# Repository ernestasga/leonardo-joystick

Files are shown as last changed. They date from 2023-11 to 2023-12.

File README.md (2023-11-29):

# Custom Arduino Leonardo Joystick
This is a custom Arduino Leonardo Joystick. It is based on the Arduino Leonardo and uses the Arduino Joystick library.

| | | |
|:---:|:---:|:---:|
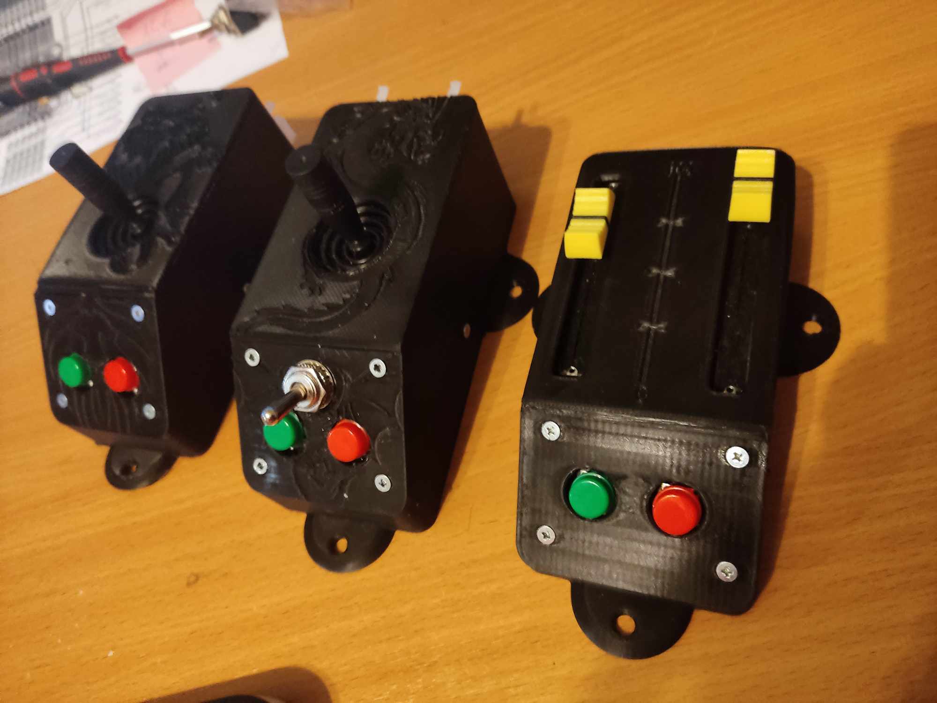
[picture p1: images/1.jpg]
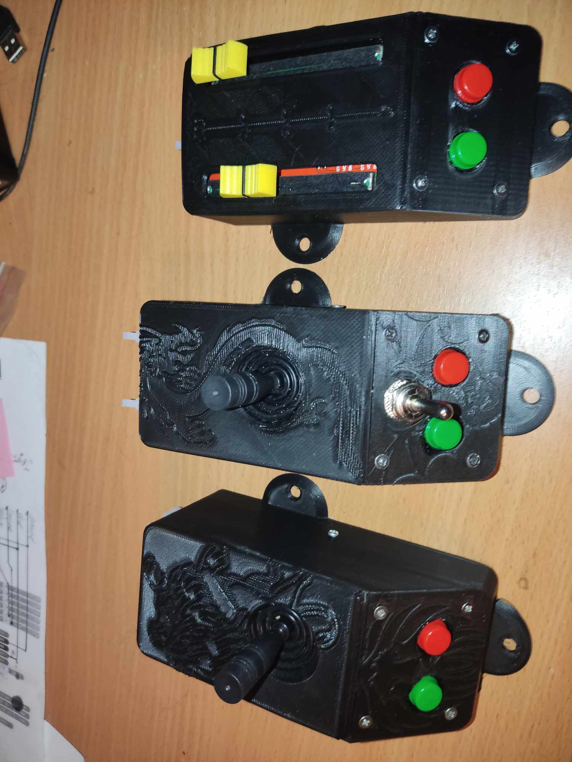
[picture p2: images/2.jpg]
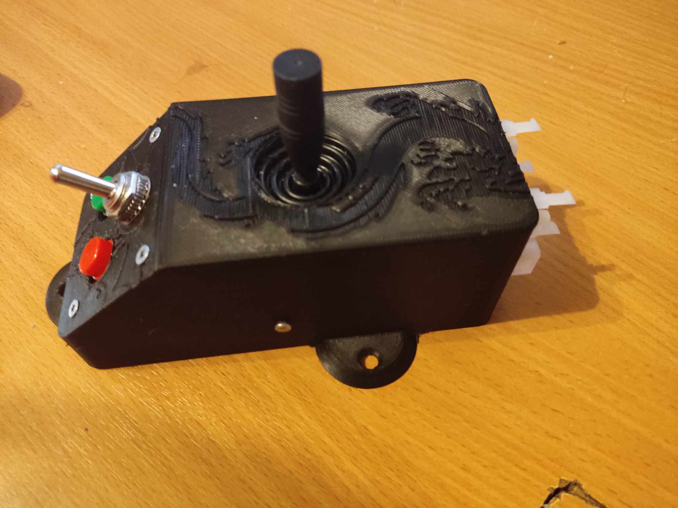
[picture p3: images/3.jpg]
|  |  ||
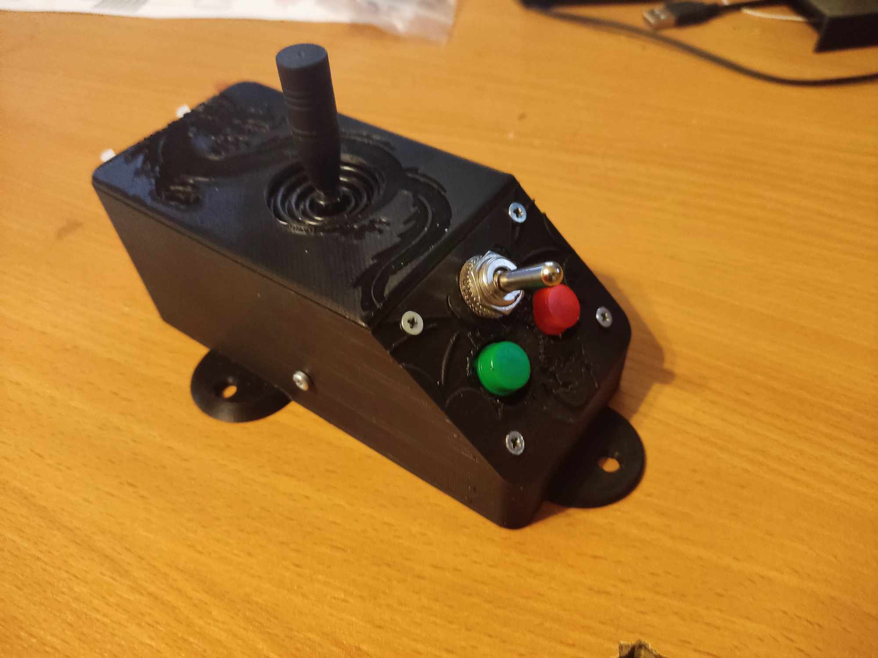
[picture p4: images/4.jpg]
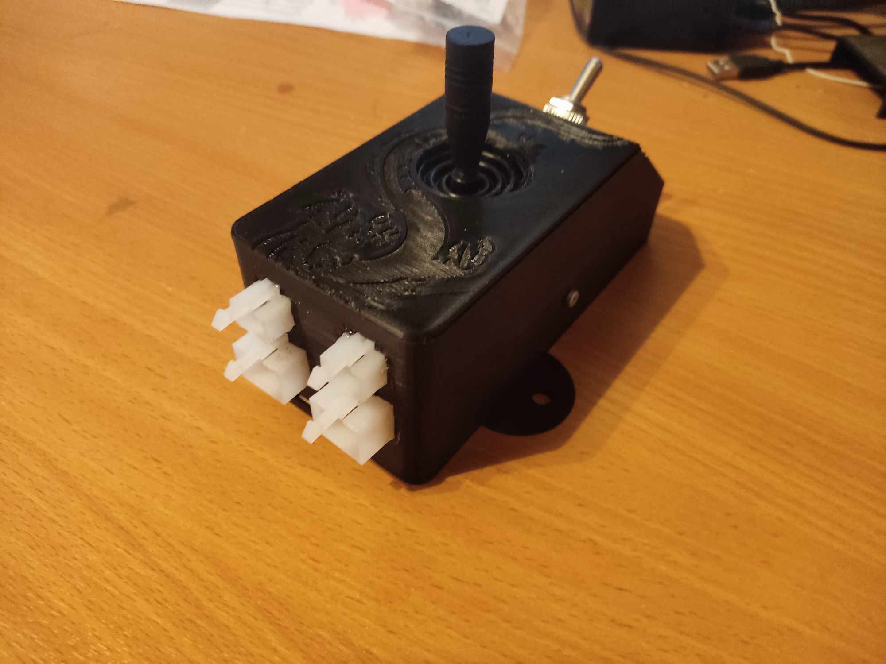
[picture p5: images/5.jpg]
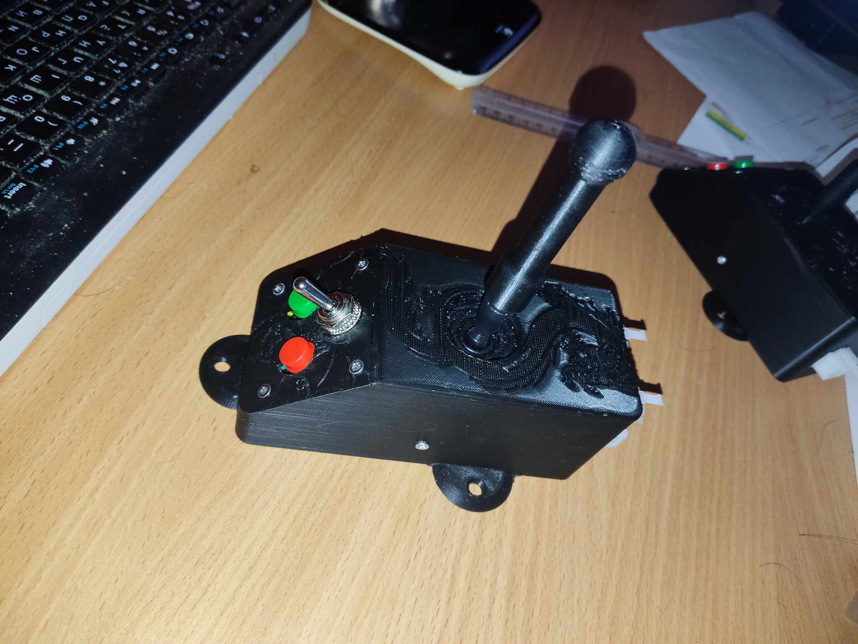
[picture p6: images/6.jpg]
|  |  |  |

## Overview
Joystick is built with accessibility and modularity in mind.

## Parts
- [Arduino Leonardo](https://store.arduino.cc/products/arduino-leonardo-without-headers)
- 2x [2-axis potentiometers](https://www.aliexpress.com/item/1005005203342038.html)
- 2x [slider potentiometers](https://www.aliexpress.com/item/1005005434366252.html)
- 6x [tactile arduino buttons with caps](https://www.aliexpress.com/item/1005005708818336.html)
- 1x [mini toggle switch](https://www.aliexpress.com/item/1005004692981776.html)
- [6 core cable](https://www.aliexpress.com/item/4000570401041.html) (for connecting the joystick and buttons, ~5M)
- [2 core cable](https://www.aliexpress.com/item/4000570401041.html) (for connecting the external buttons, ~5M)
- 5x [6-pin connectors](https://www.aliexpress.com/item/1005004615687476.html)
- 2x [2-pin connectors](https://www.aliexpress.com/item/1005004615687476.html)
- 16x M3 screws (12x for button plates, 4x for joystick raisers)
- 4x M3 nuts (for securing joystick raisers)
- Some super glue

## 3D Printed Parts
- **Main case**: Contains the controller board, a joystick and 3 buttons. There are also 2 additional ports for extra joysticks and 2 ports for external buttons.
    * Main Case.stl
    * Top Cover.stl
    * Buttons Plate.stl (Print in ABS. Screw threads don't work well in PLA)
    * Joystick Raiser.stl
    * 4x Arduino Pin Cap.stl (For pushing down the Arduino board)

- **Secondary case**: Contains a joystick and 2 buttons. Connected with one of 6-pin ports on main case.
    * Secondary Case.stl
    * Top Cover.stl
    * Buttons Plate.stl (Print in ABS. Screw threads don't work well in PLA)
    * Joystick Raiser.stl

- **Slider case**: Contains 2 slider potentiometers and 2 buttons. Connected with one of 6-pin ports on main case.
    * Slider Case.stl
    * Top Cover.stl
    * Buttons Plate.stl (Recommended to print in ABS)

## Assembly
1. Solder the wires to the Arduino Leonardo board. Wiring rules are in the `Arduino Leonardo Wiring.pdf` file.
2. Connect other ends of wires to 6-pin and 2-pin connectors on the main case. Lookup `Connector Color Coding.png` for the color coding.
3. Insert the Arduino Leonardo board into the main case. Use 4x Arduino Pin Caps to push the board down.
4. Prepare joystick raisers:
    1. Insert M3 nuts into the inside of the joystick raisers. Use super glue to secure them.
    2. Screw the joystick raisers to the main case.
5. Insert the joystick into and connect it to the ardunio board. When lined up with top cover, super guide the joystick raiser.
6. Connect the 6-pin connectors to the secondary and slider cases. (Optional) Connect the 2-pin connectors to the external buttons.

For secondary case and slider case, you can use the same steps as for the main case. The only difference is that you don't need to insert the Arduino board into the case and there are much less wires to connect.

## Flashing the Arduino
1. Download and install the Arduino IDE from https://www.arduino.cc/en/Main/Software
2. Install the Arduino Joystick library:
    1. Download the Arduino Joystick library from [Github Repo](https://github.com/MHeironimus/ArduinoJoystickLibrary/releases/)
    2. Extract the library to `~/Documents/Arduino/libraries/`
3. Open the `code/main/main.ino` file in the Arduino IDE
4. Select "Arduino Leonardo" from the Tools > Board menu
5. Select your Arduino Leonardo's serial port from the Tools > Port menu
6. Invert axes and modify deadzones if needed at lines 95-100.
7. Press the "Upload" button

## Customization
### Code
You can customize the joystick functionality by modifying the `code/main/main.ino` file. You can change the button mappings, invert axes, modify deadzones and more.

### 3D Models
You can modify the 3D models by opening the `3D/src/Joystick.3df` file in Autodesk [Fusion 360](https://www.autodesk.com/products/fusion-360/overview) or `3D/src/Joystick.step` file in any other 3D modeling software.

Specifically, you may want to modify case engravings. They can be found at the end of each component' timeline. SVG files for engravings can be found in the `3D/src/svg` folder.

## Usage
The joystick is recognized as a standard HID USB joystick. You can use it in any game or application that supports joysticks.

Here is a list of complimentary software that can be used with the joystick for accessibility purposes:
- [Xpadder](https://www.xpadder.com/) - Allows you to map keyboard keys and mouse button actions to your game controller buttons.
- [x360ce](https://www.x360ce.com/) - Allows you to emulate an Xbox controller with any controller.
- [JoyToKey](https://joytokey.net/en/) - Allows you to map keyboard keys and mouse button actions to your game controller buttons.

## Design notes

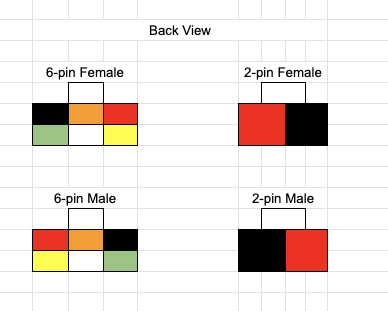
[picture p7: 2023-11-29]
Connector Color Coding.png

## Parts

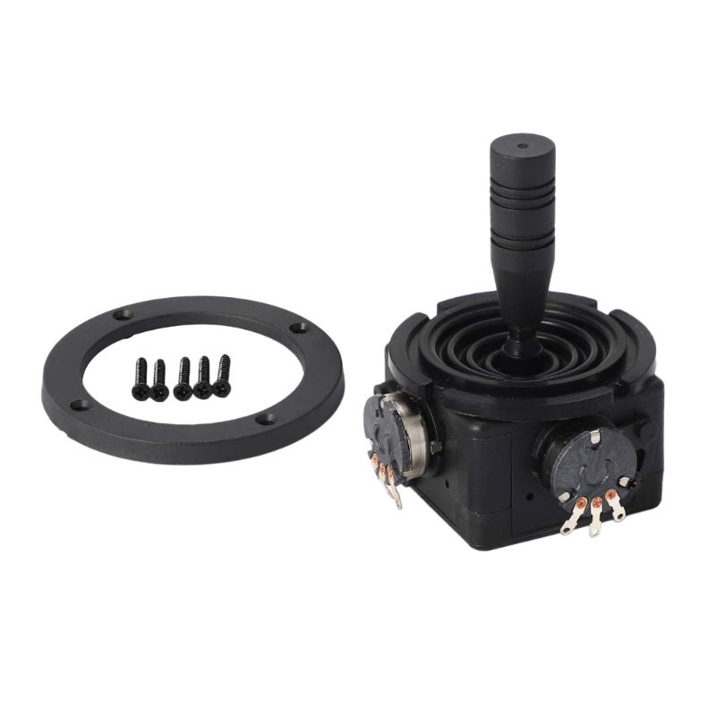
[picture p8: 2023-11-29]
parts/Joystick JH-D202X-R4.png

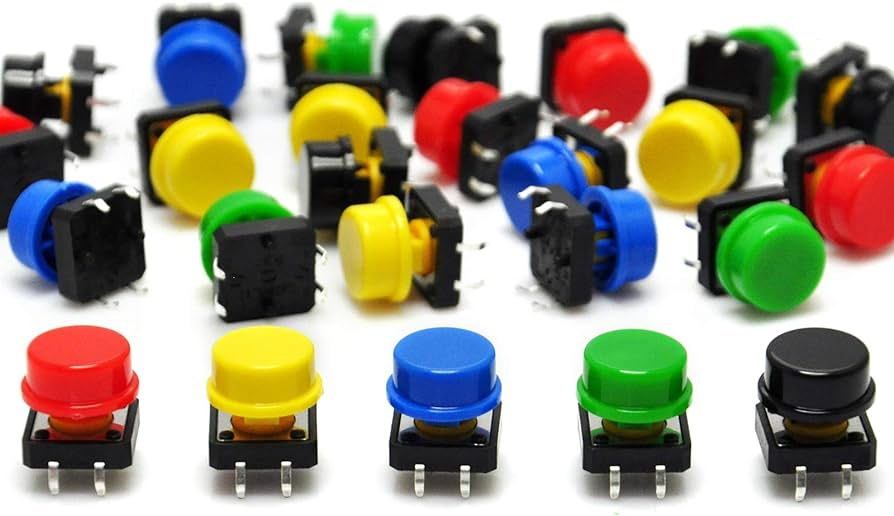
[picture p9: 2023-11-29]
parts/Buttons.png

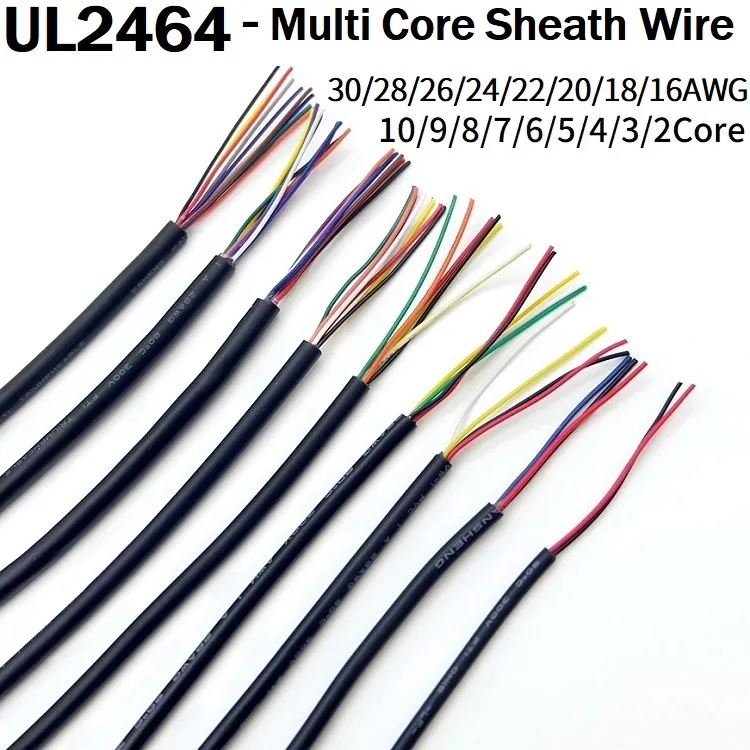
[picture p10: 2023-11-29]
parts/Cables.png

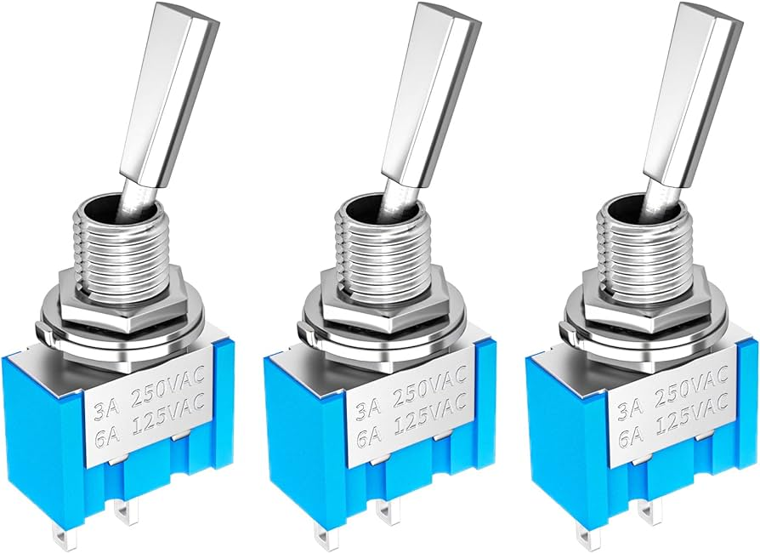
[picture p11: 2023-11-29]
parts/Mini Toggle Switch.png

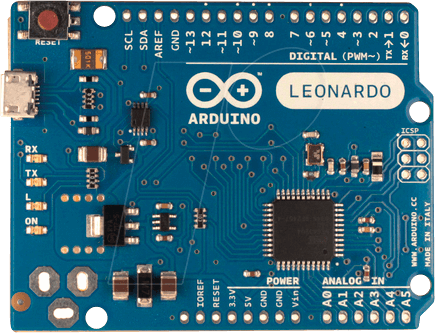
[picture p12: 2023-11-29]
parts/Arduino Leonardo.png

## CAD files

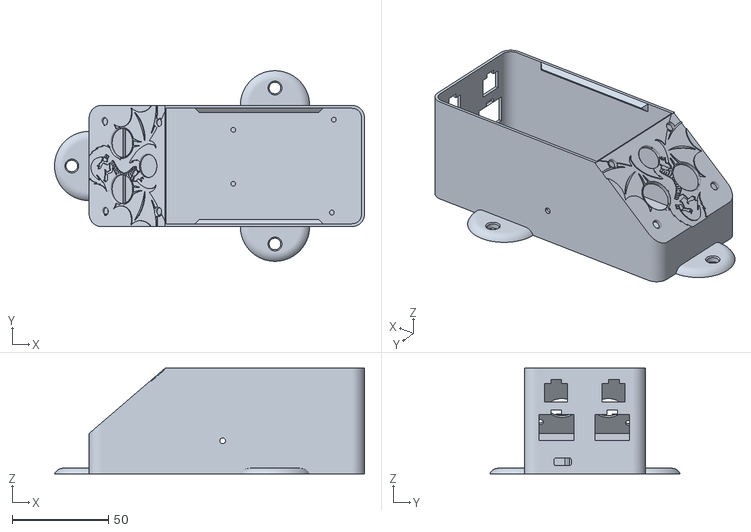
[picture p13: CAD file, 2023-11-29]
3D/outputs/main_case/Main Case.stl
161.0 x 99.0 x 55.0

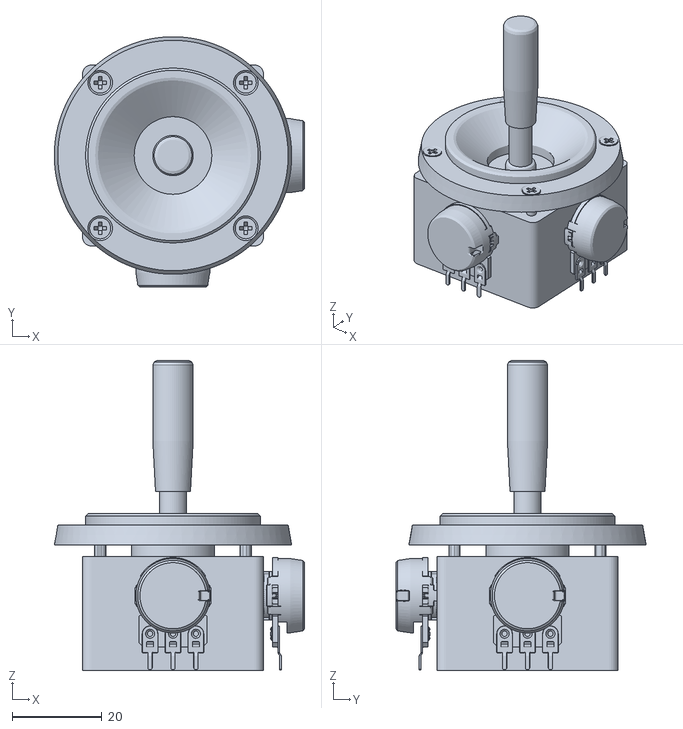
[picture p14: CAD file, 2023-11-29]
3D/components/JH-D202X-R4 2-axis Potentiometer.stl
55.9 x 55.9 x 69.2

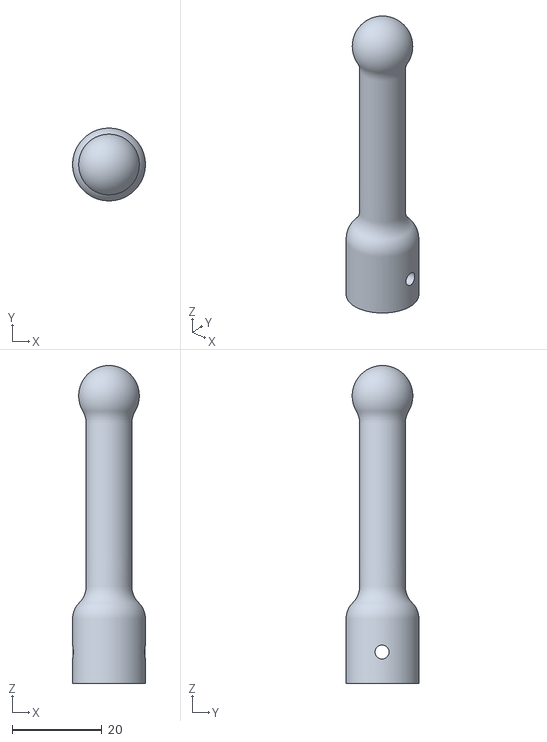
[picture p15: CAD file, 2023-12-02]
3D/outputs/main_case/Joystick Extender.stl
16.2 x 16.2 x 70.8

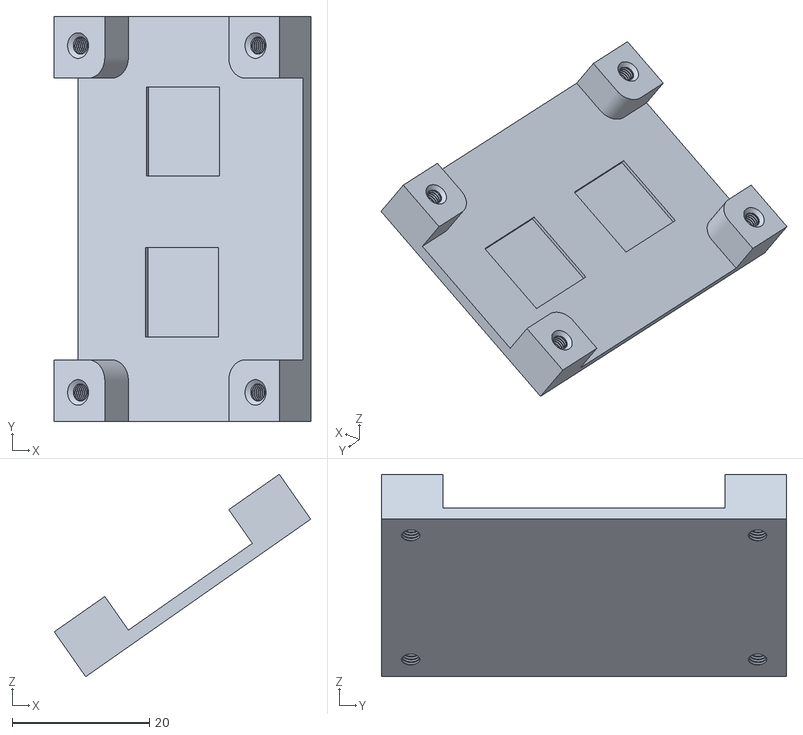
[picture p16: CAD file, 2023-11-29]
3D/outputs/slider_case/Buttons Plate.stl
37.4 x 59.1 x 29.5

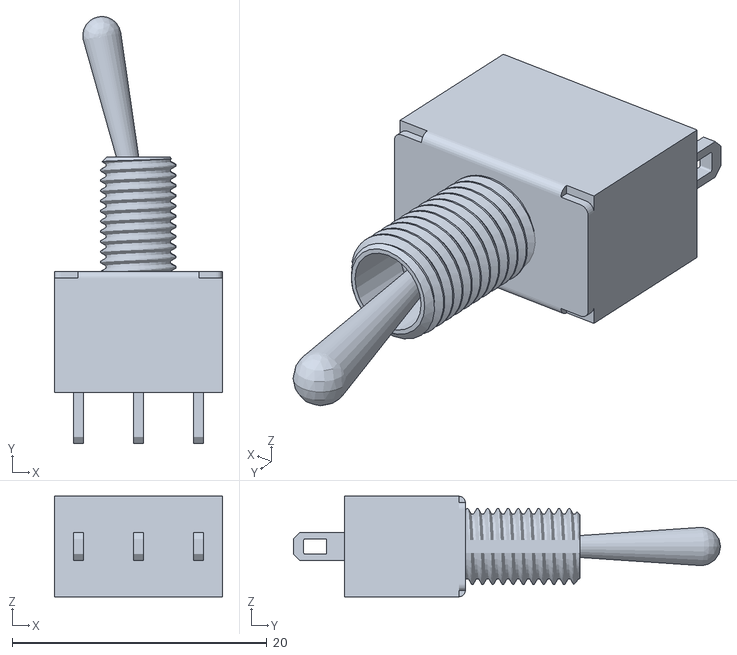
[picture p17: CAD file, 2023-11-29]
3D/components/MTS-102 Toggle Switch.stl
13.2 x 33.5 x 7.90

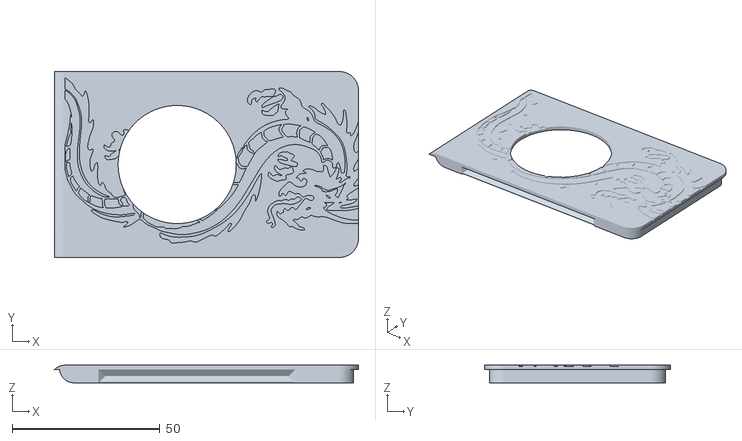
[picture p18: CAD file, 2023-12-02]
3D/outputs/main_case/Top Cover.stl
103.0 x 63.0 x 6.00

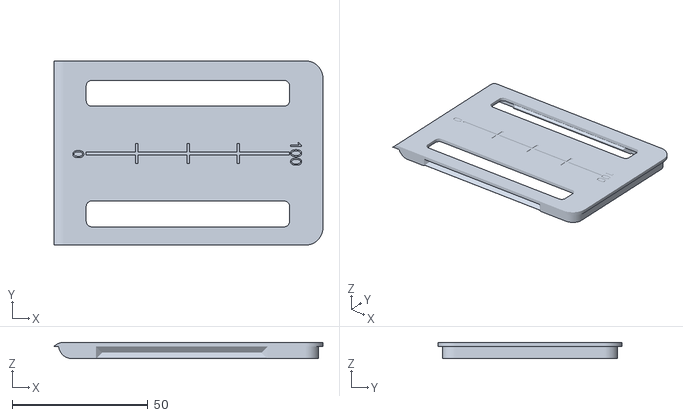
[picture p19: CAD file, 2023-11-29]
3D/outputs/slider_case/Top Cover.stl
99.2 x 68.0 x 6.00

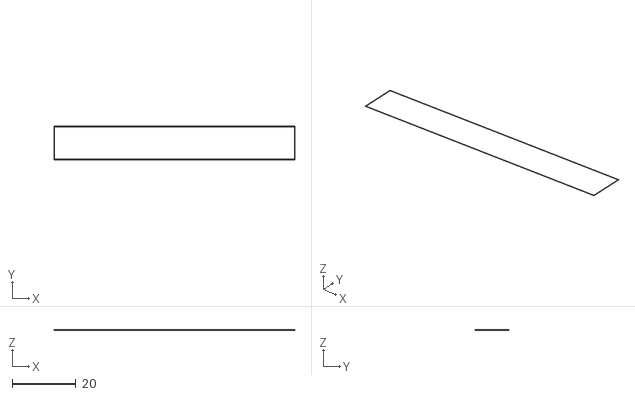
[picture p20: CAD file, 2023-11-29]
3D/components/Slider Potentiometer.stl
75.9 x 10.6 x 0.01

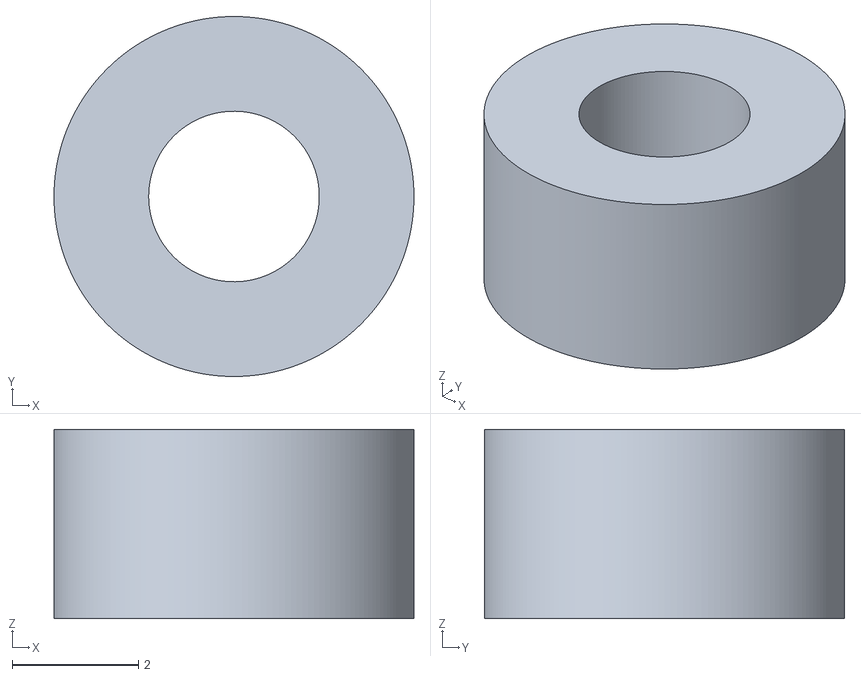
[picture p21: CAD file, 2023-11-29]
3D/outputs/main_case/Arduino Pin Cap.stl
5.70 x 5.70 x 3.00

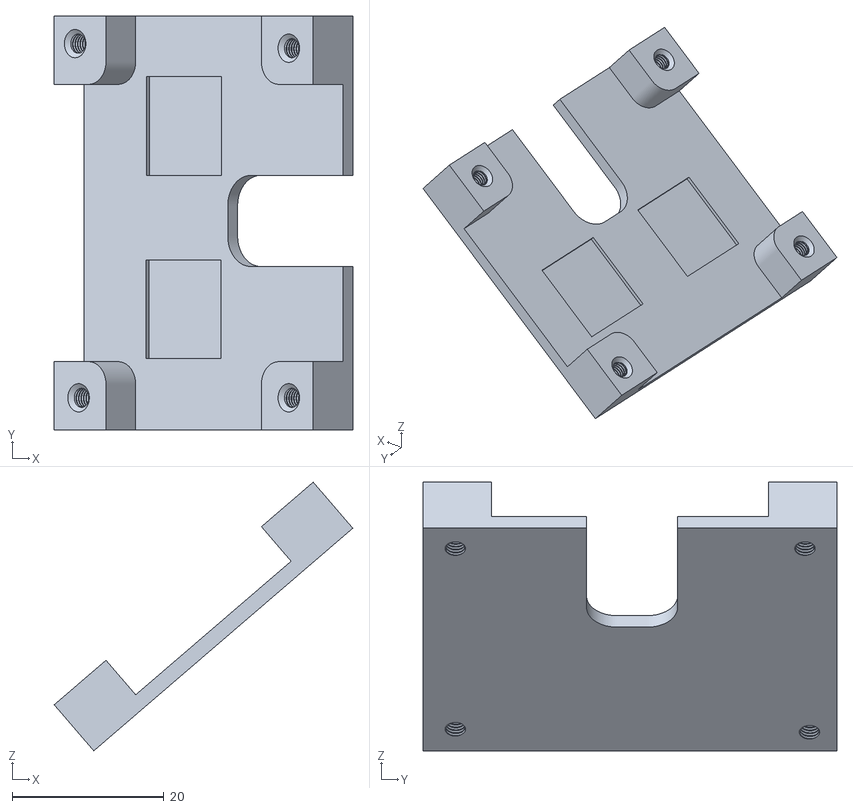
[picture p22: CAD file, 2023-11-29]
3D/outputs/secondary_case/Buttons Plate.stl
39.3 x 54.5 x 35.4

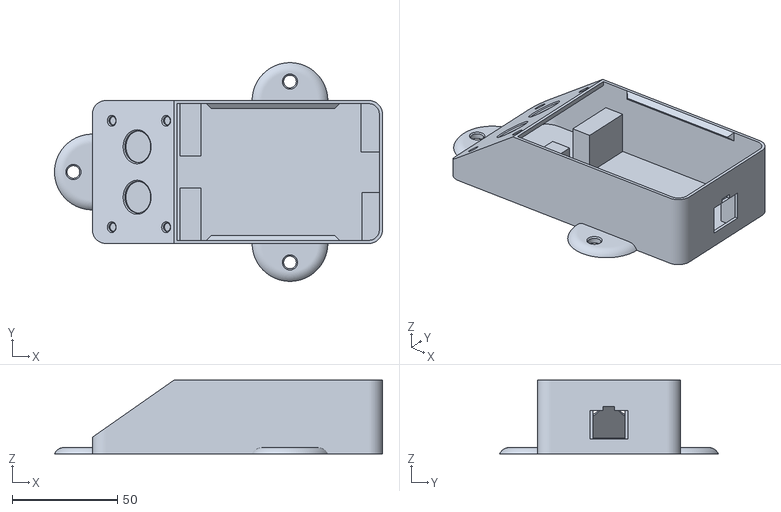
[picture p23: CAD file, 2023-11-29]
3D/outputs/slider_case/Slider Case.stl
156.0 x 104.0 x 35.0

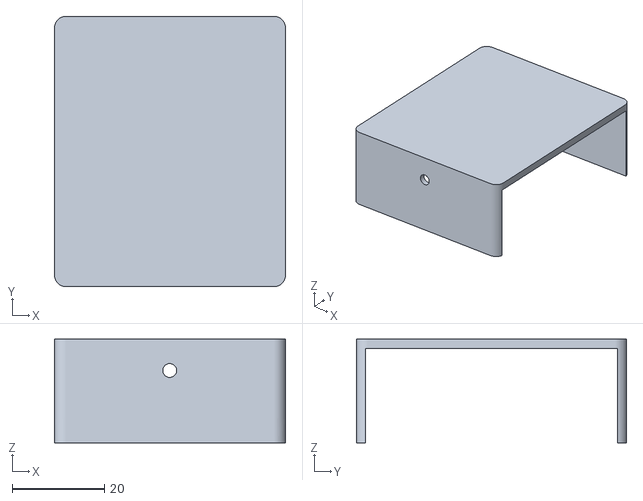
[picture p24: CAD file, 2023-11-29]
3D/outputs/secondary_case/Joystick Raiser.stl
50.0 x 58.5 x 22.5

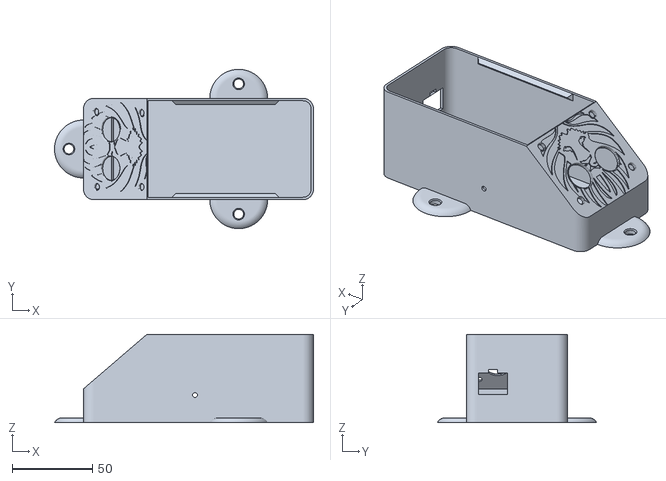
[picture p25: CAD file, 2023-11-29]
3D/outputs/secondary_case/Secondary Case.stl
161.0 x 99.0 x 55.0

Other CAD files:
3D/src/Joystick.step
3D/outputs/secondary_case/Top Cover.stl
3D/outputs/main_case/Buttons Plate.stl

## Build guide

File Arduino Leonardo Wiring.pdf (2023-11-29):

Arduino Leonardo Wiring
for
Custom Joystick

Joystick Main Case

6x Wire
Black | GND
Red | +5V
Orange | A0
White | A1
Yellow | D2
Green | D3
Blue | D4

Joystick Secondary Case

6x Wire
Black | GND
Red | +5V
Orange | A2
White | A3
Yellow | D5
Green | D6

Slider Case

6x Wire
Black | GND
Red | +5V
Orange | A4
White | A5
Yellow | D7
Green | D8

External Button 1

2x Wire
Black | GND
Red | D9

External Button 2

2x Wire
Black | GND
Red | D10

Requirements:
1x - Arduino Leonardo
3x - 6 wire cables
2x - 2 wire cables
1x - 1 wire (blue) | 1 extra blue wire is for main joystick’ 3rd button

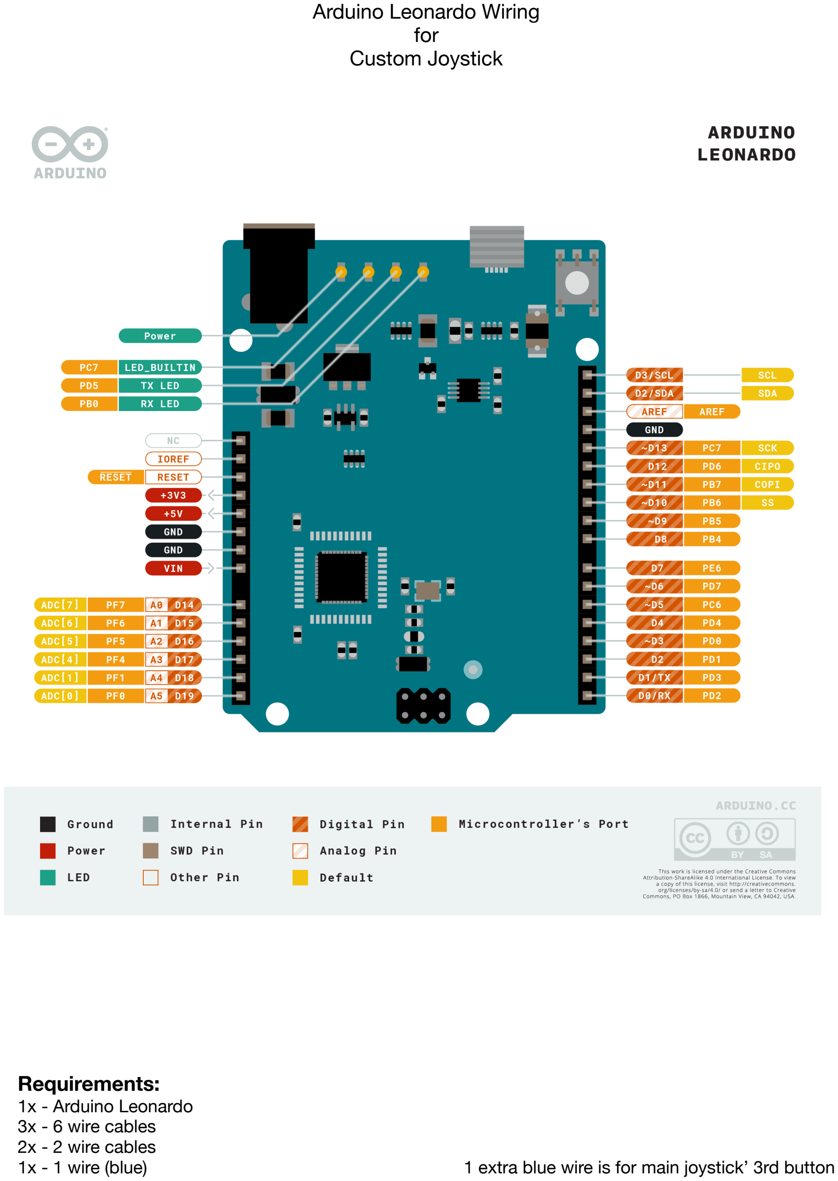
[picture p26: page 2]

Arduino Leonardo Wiring
for
Custom Joystick

Requirements:
1x - Arduino Leonardo
3x - 6 wire cables
2x - 2 wire cables
1x - 1 wire (blue) | 1 extra blue wire is for main joystick’ 3rd button

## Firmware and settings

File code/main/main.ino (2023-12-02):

/*
* Custom Modular Joystick
* Modular Accessible Joystick. This version is for 3 interconnectable modules.
* Main Module has 1 2-axis Joystick, 3 Buttons.
* Secondary Module has 1 2-axis Joystick, 2 Buttons.
* Slider Module has 2 Sliders, 2 Buttons.
* Invert axes and modify deadzones if needed at lines 95-100.
* -----------------------
* Controller: Arduino Leonardo
* ----------------------------
* Author:  Ernestas G. (github.com/ernestasga)
* Date:    2023-10-22
* Version: 1.0.0
*/

#include <Joystick.h>

/*
* Analog Joystick class
* @param xPin - X axis pin
* @param yPin - Y axis pin
* @param deadzone - deadzone % for the joystick. 0.0 - 1.0
* @param invertXAxis - (Optional) Invert the X axis. Default is false.
* @param invertYAxis - (Optional) Invert the Y axis. Default is false.
*/
class AnalogJoystick {
  private:
    byte pinX, pinY;
    float deadzonePercentage;
    bool invertX, invertY;
    int applyDeadzone(int value) {
      int center = 512;  // Assuming the joystick centers around 512 (analog range: 0-1023)
      int range = 512;   // Max deviation from center
      int deadzone = static_cast<int>(range * deadzonePercentage);
      if (value > (center + deadzone) || value < (center - deadzone)) {
        return value;
      }
      return center;
    }
    int invertAxis(int value, bool invert) {
      return invert ? 1023 - value : value;
    }

  public:
    AnalogJoystick(byte xPin, byte yPin, float deadzone, bool invertXAxis = false, bool invertYAxis = false)
    : pinX(xPin), pinY(yPin), deadzonePercentage(deadzone), invertX(invertXAxis), invertY(invertYAxis) {}

    int readX() {
      return invertAxis(applyDeadzone(analogRead(pinX)), invertX);
    }
    int readY() {
      return invertAxis(applyDeadzone(analogRead(pinY)), invertY);
    }
};

/*
* Slider class
* @param pin - slider pin
* @param invertSlider - (Optional) Invert the slider value. Default is false.
*/
class Slider {
  private:
    byte pin;
    bool invert;

    int invertValue(int value) {
      return invert ? 1023 - value : value;
    }

  public:
    Slider(byte _pin, bool invertSlider = false) : pin(_pin), invert(invertSlider) {}
    int readValue() {
      return invertValue(analogRead(pin));
    }
};

/*
* Button class
* @param pin - button pin
*/
class Button {
  private:
    byte pin;
  public:
    Button(byte _pin) : pin(_pin) {
      pinMode(pin, INPUT_PULLUP);
    }
    bool isPressed() {
      return digitalRead(pin) == LOW;
    }
};

// Main Joystick
AnalogJoystick joystick1(A0, A1, 0.025, true, true); // 2.5% deadzone
// Secondary Joystick
AnalogJoystick joystick2(A3, A2, 0.025, true, false); // 2.5% deadzone
// Sliders
Slider slider1(A4, true);
Slider slider2(A5);
// Buttons
Button buttons[] = {Button(2), Button(3), Button(4), Button(5), Button(6), Button(7), Button(8), Button(9), Button(10)};

// Initialize Joystick
Joystick_ Joystick(
  JOYSTICK_DEFAULT_REPORT_ID,   // HID Report ID
  JOYSTICK_TYPE_JOYSTICK,       // HID Type: Joystick
  9,      // Number of Buttons
  0,      // Number of Hat Switches
  true,   // X Axis
  true,   // Y Axis
  true,   // Z Axis. Used only for dummy center value
  true,   // Rx Axis
  true,   // Ry Axis
  true,   // Rz Axis. Used only for dummy center value
  false,  // Rudder
  true,   // Throttle
  true,   // Accelerator
  false,  // Brake
  false   // Steering
);

void setup() {
  Joystick.begin();
}

void loop() {
  // Main Joystick
  Joystick.setXAxis(joystick1.readX());
  Joystick.setYAxis(joystick1.readY());
  
  // Secondary Joystick
  Joystick.setRxAxis(joystick2.readX());
  Joystick.setRyAxis(joystick2.readY());

  // Sliders
  Joystick.setZAxis(slider1.readValue());
  Joystick.setRzAxis(slider2.readValue());

  // Buttons
  for (int i = 0; i < 9; i++) {
    Joystick.setButton(i, buttons[i].isPressed());
  }

  // Dummy Always Center Axes
  Joystick.setThrottle(512);

  delay(1);
}

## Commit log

2023-12-02 Wider joystick hole for more motion
    [Top Cover.stl]
2023-12-02 Joystick extender
    [Joystick Extender.stl, Joystick.step]
